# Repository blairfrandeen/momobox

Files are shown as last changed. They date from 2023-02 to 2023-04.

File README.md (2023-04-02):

# The Momobox
A build-it-yourself MP3 player for toddlers, and maybe for adults too. 3D-print your own custom figurines (we call them _Momies_) and pair them with your favorite stories, songs, or audiobooks. If you have a 3D printer and the ability to solder, you can build one of these for roughly the same cost as a commercial [Toniebox](https://us.tonies.com/pages/toniebox), and without the long-term cost of ownership. Plus, the momobox and the associated momies are distinctly yours!

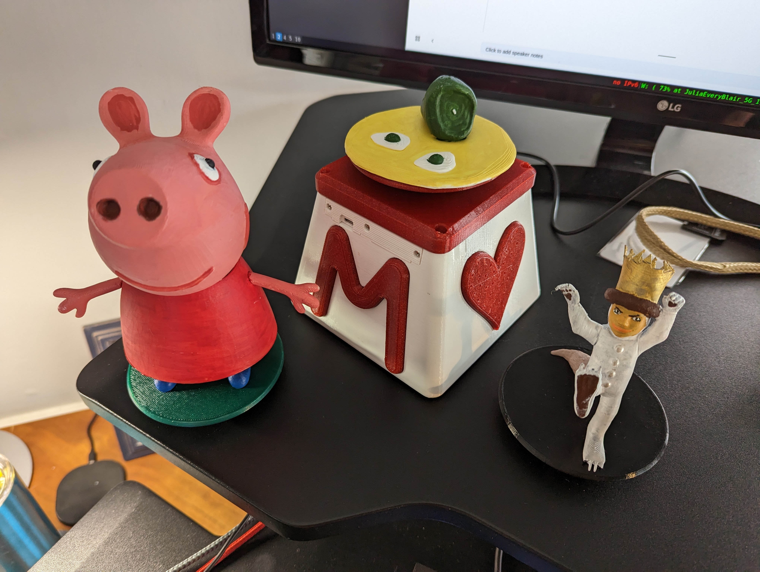
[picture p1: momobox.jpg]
Here's a momobox!


The momobox started as a toy I built for my daughter, who we call Momo, during my batch at [the Recurse Center](https://www.recurse.com). It runs on a Raspberry Pi Pico, and incorporates an RFID sensor, speaker, SD card, and a 3D-printed enclosure and momies.

## You Can Build One Too!
Take a look at the [project wiki](https://github.com/blairfrandeen/momobox/wiki) for resources and to get started. At this time the project is not fully documented - if you'd like support, encouragement, or get stuck during the build, please feel free to reach out!

## 3D Printed Components
The design for the 3D printed components lives in [OnShape](https://cad.onshape.com/documents/79b0dabc494fde770de26b57/w/b19bbc68ed3995e5b344c842/e/d2a39d4dcadbb5ff28daf759).

## Materials
Materials currently on order are stored in this [Google Sheet](https://docs.google.com/spreadsheets/d/11zDQTo5MPM0dLdLS7p9JRmXvDPAh0dKTZ6d4dLGUlPc/edit?usp=sharing). A finalized bill of materials should go in this section once an initial build configuration has been selected.

## Resources
List of learning & technical resources that can be used to complete this project:
- [Raspberry Pi Documentation](https://www.raspberrypi.com/documentation/computers/getting-started.html)
- [Uploading to Raspberry Pi Pico without Thonny](https://mikeesto.medium.com/uploading-to-the-raspberry-pi-pico-without-thonny-53de1a10da30)
- [Adafruit](https://learn.adafruit.com/) - Some beginning elex tutorials and components
- [Simple MP3 Audio Playback With Raspberry Pi Pico](https://embeddedcomputing.com/technology/processing/interface-io/simple-mp3-audio-playback-with-raspberry-pi-pico) - Good tutorial to start working next.
- [Raspberry Pi Pico Tutorial with battery hookup](https://www.raspberrypi.com/tutorials/raspberry-pi-pico-iron-man-arc-reactor/)
- [Tom's Hardware Pico Page](https://www.tomshardware.com/news/raspberry-pi-pico-tutorials-pinout-everything-you-need-to-know)
- [Raspberry Pi Projects Page](https://projects.raspberrypi.org/en/projects/getting-started-with-the-pico) - Getting started with Pico tutorial

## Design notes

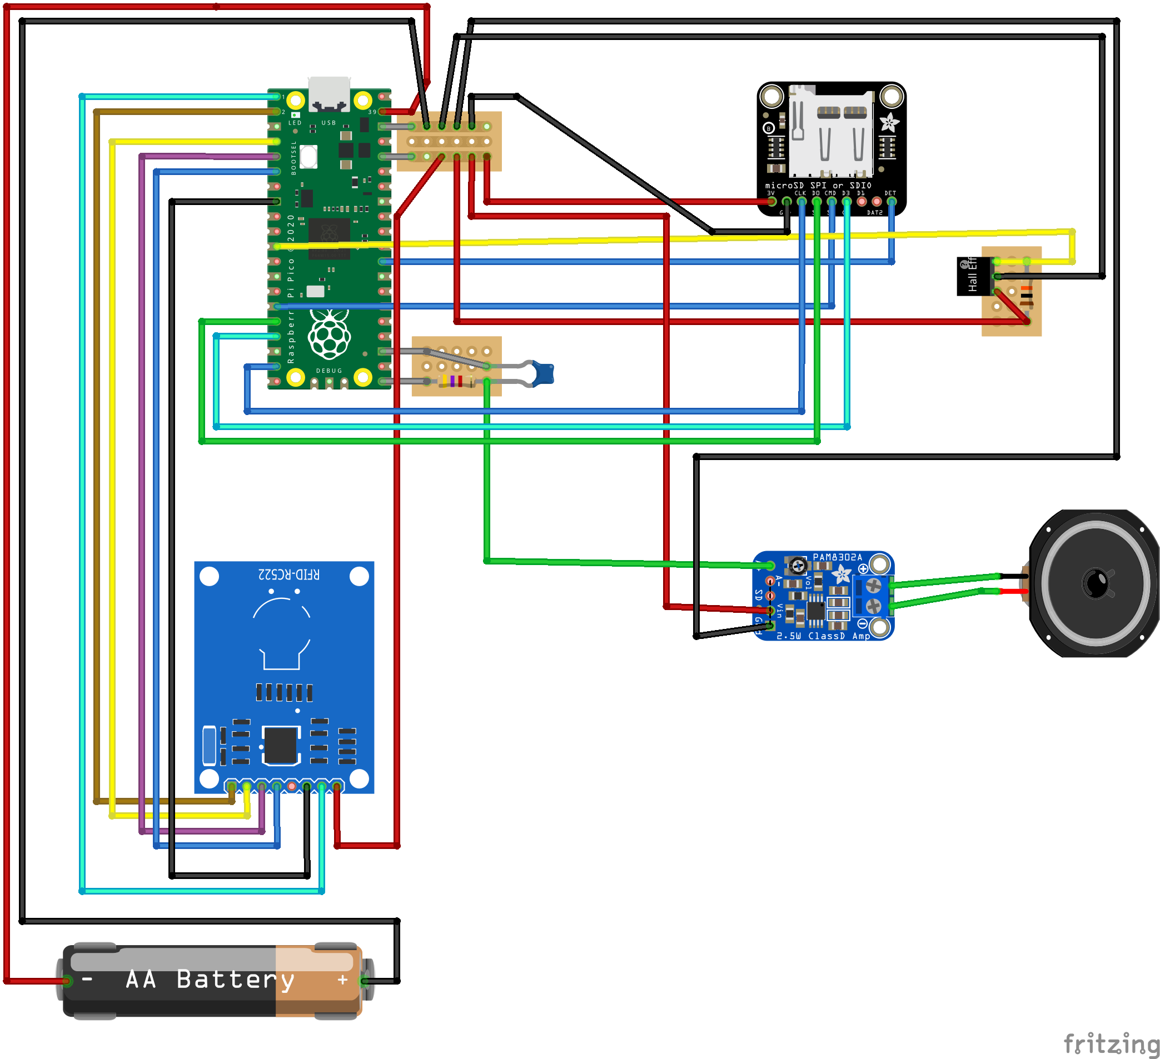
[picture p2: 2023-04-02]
schematics/momobox_bb.png

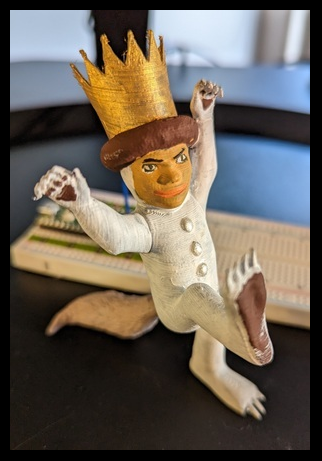
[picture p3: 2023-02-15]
wildmax.jpg

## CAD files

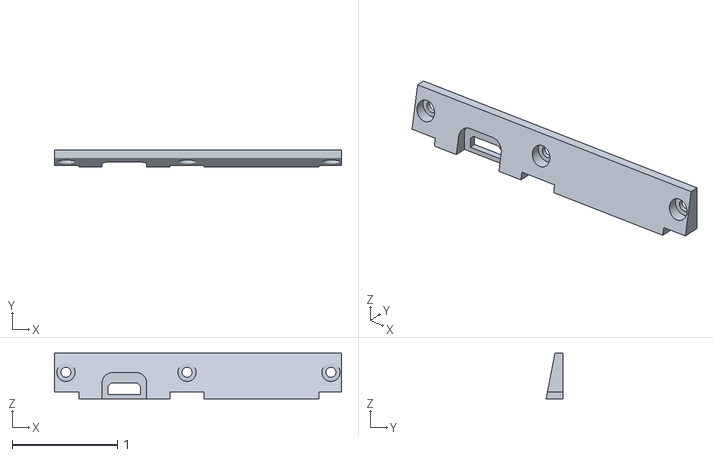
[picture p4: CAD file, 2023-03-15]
packaging/momobox_base_coverplate.stl
2.73 x 0.161 x 0.435

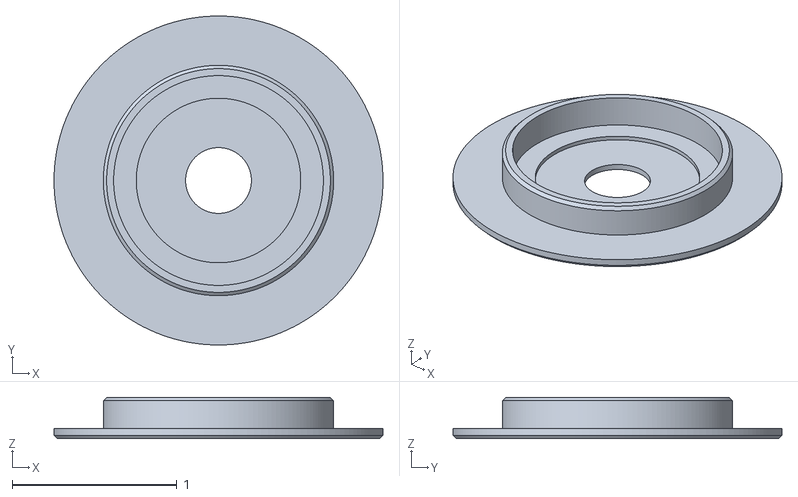
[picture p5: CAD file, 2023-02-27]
stage_cap.stl
2.00 x 2.00 x 0.25

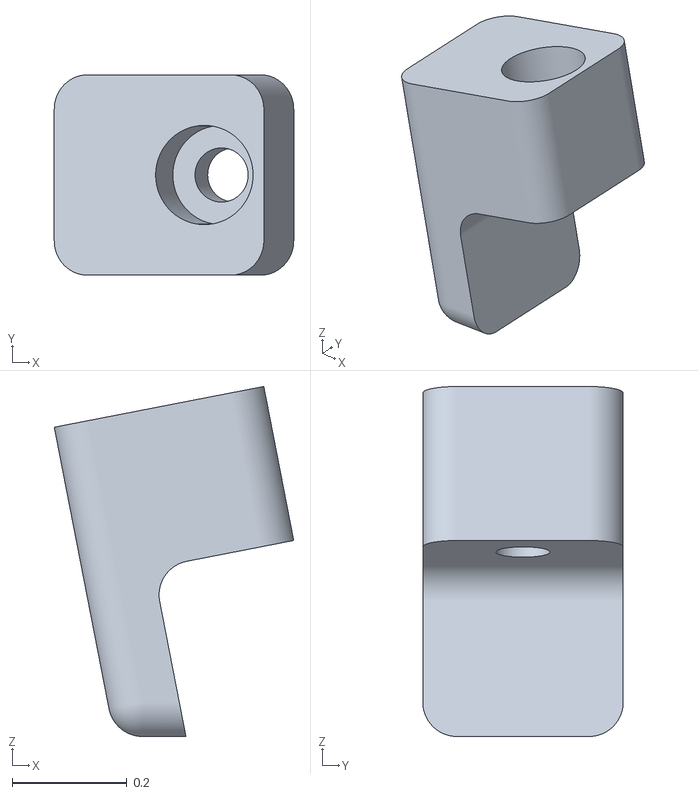
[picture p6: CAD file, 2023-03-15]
packaging/momobox_speaker_clip.stl
0.418 x 0.35 x 0.611

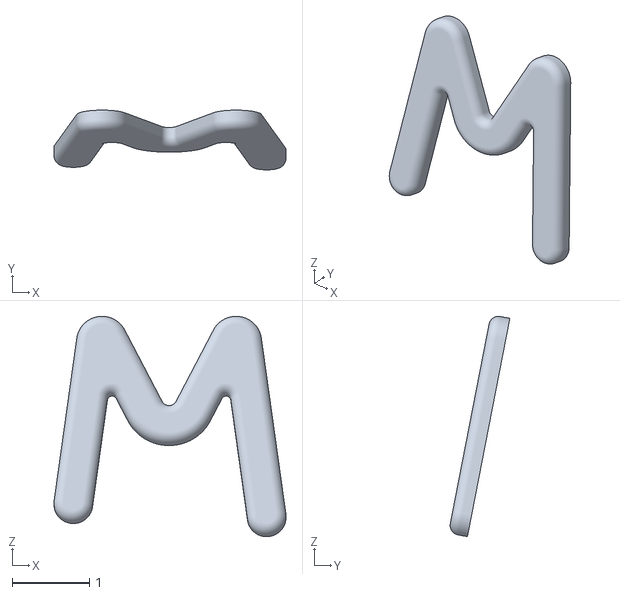
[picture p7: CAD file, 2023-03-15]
packaging/momobox_m.stl
3.00 x 0.773 x 2.85

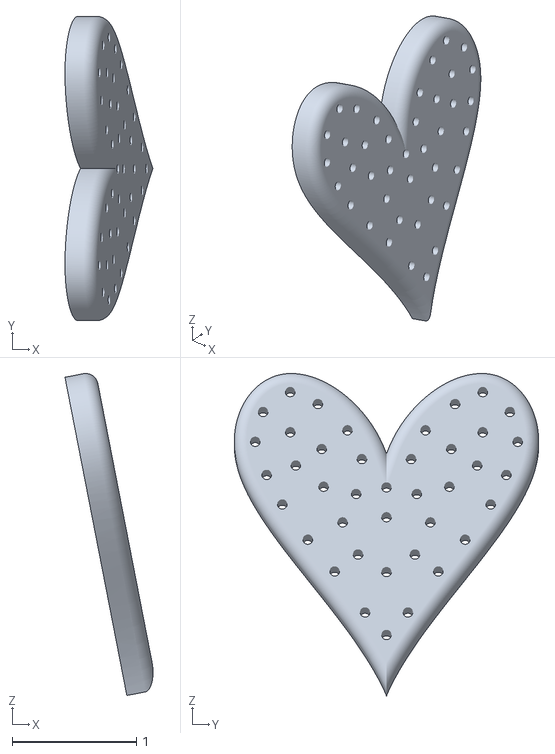
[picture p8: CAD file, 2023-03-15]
packaging/momobox_heart_front.stl
0.708 x 2.45 x 2.59

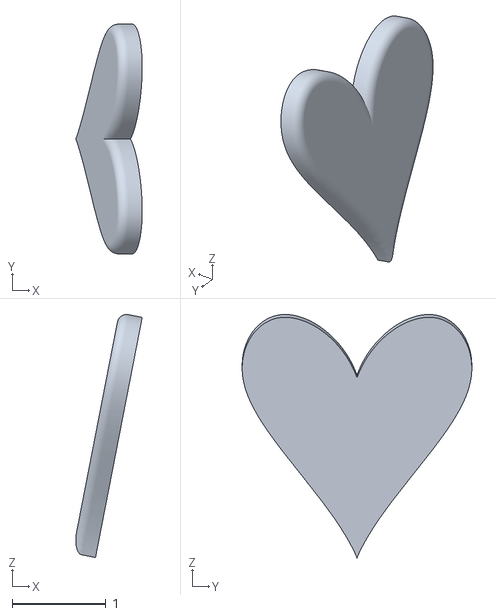
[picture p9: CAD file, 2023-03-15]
packaging/momobox_heart_back.stl
0.708 x 2.45 x 2.59

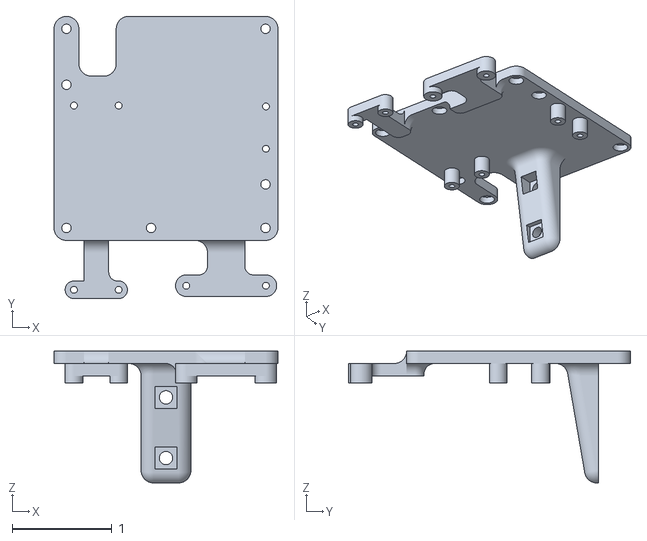
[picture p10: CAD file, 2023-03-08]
packaging/momobox_board_mount.stl
2.25 x 2.83 x 1.33

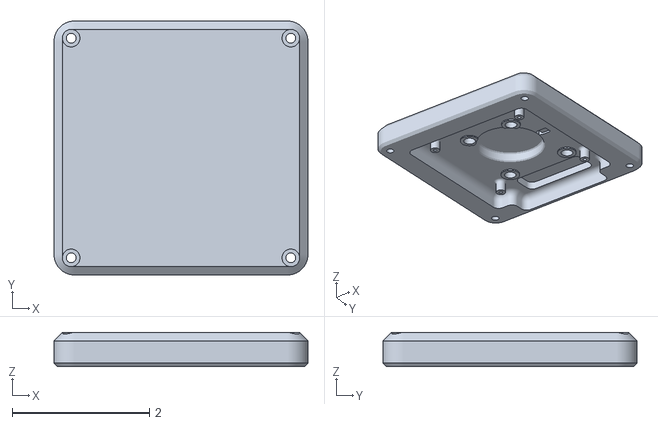
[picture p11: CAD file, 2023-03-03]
packaging/momobox_base_lid.stl
3.70 x 3.70 x 0.5

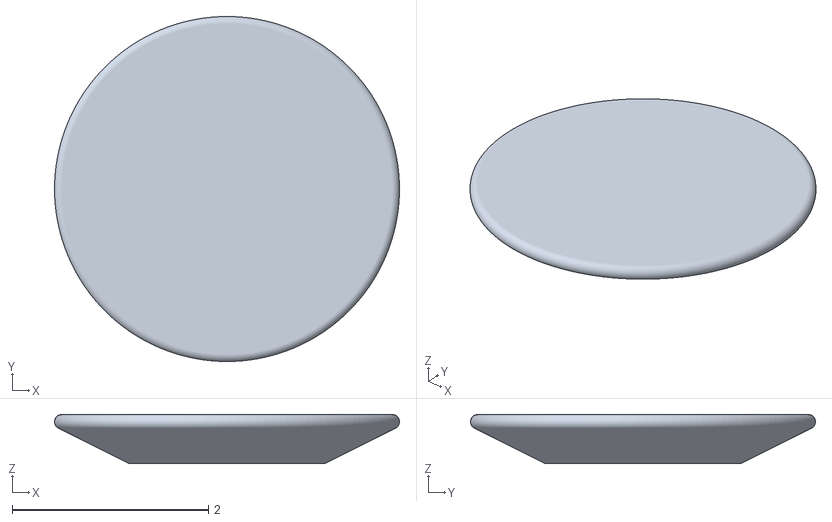
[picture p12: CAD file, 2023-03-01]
packaging/stage_top.stl
3.51 x 3.51 x 0.5

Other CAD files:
packaging/momobox_m_mirror.stl
packaging/stage_cap.stl

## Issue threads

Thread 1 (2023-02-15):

Start Bill of Materials

blairfrandeen, 2023-02-15:
Start a basic bill of materials, either in markdown table or csv format. Should include the following columns:
- Component Name
- Quantity Required
- Description or Notes
- Source (link to purchase)
- Price

Okay for this to be wrong / incomplete. Also okay for components to be identified as needed and not fully specified. Multiple options for components also okay.

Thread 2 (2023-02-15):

Set up MicroPython Development Environment

blairfrandeen, 2023-02-15:
The "official" method of talking to the Raspberry Pi Pico is through the Thonny editor, which isn't my preferred development environment.

Check out [this article](https://mikeesto.medium.com/uploading-to-the-raspberry-pi-pico-without-thonny-53de1a10da30) and see if I can't get Raspberry Pi Pico to talk directly to VSCode, which is my editor of choice.

blairfrandeen, 2023-02-24:
Happy with the current approach of editing on my local machine, and then pushing files to the pico which is connected at `/media/blair/CIRCUITPY`. CircuitPy is more friendly to this approach than MicroPython.

Closed 2023-02-24.

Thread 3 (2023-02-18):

Pi Pico Basics

blairfrandeen, 2023-02-18:
Need to learn to program some fundamentals on the Pi. Issue is closed when I can do the following:

- [ ] control a program by opening or closing a physical switch (or connect a wire on the breadboard)
- [ ] write and retrieve a value that is persistently stored on the Pi
- [ ] copy a file from my computer to the Pi
- [ ] read from a file on the Pi
- [ ] delete a file from the Pi

blairfrandeen, 2023-02-18:
- [ ] implement logging on the Pi
- [ ] crash a program and then retrieve the stack trace

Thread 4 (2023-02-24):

Box Lid Design Issues

blairfrandeen, 2023-02-24:
- [x] Magnet needs to be positively secured to top of lid (maybe just use superglue)
- [x] Bosses for inserts need to be larger diameter so they don't deform when insert installed
- [x] Verify positive separation between magnet and RC522 board
- [x] Need clocking feature between lid & base
- [x] Make material between magnet and top of lid as thin as possible
- [x] Not enough wire routing space for RC522 harness

Closed 2023-03-16.

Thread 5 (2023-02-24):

Try architecture without hall sensor

blairfrandeen, 2023-02-24:
Current setup for board includes a hall effect sensor, that toggles when magnets are connected. It may be simpler to just keep querying the RFID board, and if the RFID chip has been removed, then stop playing.

Should be functionally the same, but may be worse for power consumption, which so far hasn't been modeled or thought about.

blairfrandeen, 2023-03-16:
Tried this, and it's not the right way to go.

Having the RFID sensor continually querying to check for status, whether playing or not, is not going to be great for power consumption. I got it to work (code didn't get uploaded to GitHub yet), and the unit was very unresponsive. Took about 3 seconds from removing the Momie from the top of the box until it stopped playing; hall sensor in contrast is practically instantaneous.

Closed 2023-03-16.

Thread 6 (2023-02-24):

Speaker Mount points don't work

blairfrandeen, 2023-02-24:
Speaker mount points are not easy to work with; no good tool access, not even worth trying to get the square nuts into the bottom mount points. Needs to be rethought.

Best idea so far: Passive slot at the bottom of the box that accepts the speaker flange. Maybe keep improved screw bosses near opening of top of box, but there is also an option to make a flexured post or latch to simply snap the speaker into place.

blairfrandeen, 2023-03-15:
Fixed this on V8 of the enclosure. Speaker is secure. 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

Closed 2023-03-15.

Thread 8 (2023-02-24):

Incorporate Battery

blairfrandeen, 2023-02-24:
Need to incorporate a battery so that momobox runs wirelessly.

blairfrandeen, 2023-03-16:
So far I've only incorporated AA batteries. At this point they need to be manually removed and recharged, which requires removing the lid from the top of the box; not ideal, but workable for MVP.

Closed 2023-03-16.

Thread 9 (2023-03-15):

High Pitched audio whine

blairfrandeen, 2023-03-15:
Good explanation and possible solution here: https://forums.adafruit.com/viewtopic.php?t=188012

And here:
https://forums.adafruit.com/viewtopic.php?f=8&t=187616#p909859

Need to order some 10nF and 100nF capacitors and check my resistor supply, then check on a breadboard

blairfrandeen, 2023-03-21:
Using a 10k resistor and a 100nF (0.1 μF) capacitor seems to work! Leaving open until fully documented.

blairfrandeen, 2023-04-02:
Documented in 979b3bd

Closed 2023-04-02.

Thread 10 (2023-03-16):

Lid and board mount design issues

blairfrandeen, 2023-03-16:
- [ ] Board mount fasteners to lid are not accessible. Removing the board mount requires partial removal of the pico and the SD card board. Thru-holes have been added to the board mount, and corresponding bosses need to be added to the lid.
- [ ] Battery clip blocks board mount fasteners on back of board
- [ ] Harness routing features, particularly for RFID harness, should be added to ensure that nothing gets pinched when the lid is closed.

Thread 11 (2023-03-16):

Implement replacement for heat-set inserts

blairfrandeen, 2023-03-16:
Heat-set inserts are great, and also expensive. They cost about $17 on McMaster, and I'd like to offer users a cheaper solution.

Will probably go with some sort of press-in or slot-in hex or square nuts. Currently the heat-set inserts are used in the lid to box connection and the RFID board to lid connection.

The latter could be tapped M3 fasteners since the RFID board nominally only goes on once; the lid to box connection benefits greatly from being threaded.

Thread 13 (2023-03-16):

Better volume control

blairfrandeen, 2023-03-16:
Currently the only option for volume control is to turn the screw on the audio board. End user's key stakeholder requests easier adjustment.

Not sure how to implement this easily, may take some creative thought.

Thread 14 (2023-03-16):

RFID light stays on

blairfrandeen, 2023-03-16:
Currently the red RFID board LED is on whenever the unit is powered. Nice to see that it's on, but the light is off-center and not there intentionally. One or more dedicated LEDs to communicate status would be better

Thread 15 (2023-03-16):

Box Bottom Design

blairfrandeen, 2023-03-16:
Current box design is monolithic. Looks nice, but I think there are advantages to a separate bottom:

- iterating on the box design likely doesn't require a new bottom. In the latest print the bottom took 3 hr.
- a totally flat bottom separates from the bed (warps) prematurely
- a ribbed bottom requires support material which is hard to remove.

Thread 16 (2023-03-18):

Put momobox to sleep when not being used

blairfrandeen, 2023-03-18:
The firmware runs continuously when the batteries are connected. Goal is to have the pico go into sleep mode after some amount of idle time, and then awake upon a signal from the hall sensor.

A good starting point with resources is here: https://ghubcoder.github.io/posts/deep-sleeping-the-pico-micropython/

May be better to also read this post about dormant and sleep modes: https://ghubcoder.github.io/posts/awaking-the-pico/

This is micropython based (momobox currently uses circuit python), so may not be fully applicable.

A good thing to start with is to measure the current draw from the batteries during the following operations:
- idle time
- RFID request
- playing a song
- song paused

blairfrandeen, 2023-10-17:
Some measurements made with a DMM:

Condition | Current Draw [mA]
--- | ---
Standby | 65.6
Playing | 70-110
Paused | 68.6
RFID Chip present without magnet | 70.6
Magnet present, no RFID | 69.5
RFID, no magnet, after magnet had been activated | 74
Crashed | 45

The 2X batteries I'm using have a capacity of 1500 mAh (3000 total). 3000 mAh / ~70 mA =~ 42 hours
This operating time matches our experience with the momobox so far, although we typically get to about 24-30 hours before it turns off.

It may be promising to reduce power usage by rewriting the firmware in a lower level language that isn't constantly running an interpreter. For comparison, running "blinky" in Rust only takes 22-24 mA

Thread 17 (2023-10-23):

Integrated Rechargeable Battery

blairfrandeen, 2023-10-23:
We're tired of having to swap the batteries every day. While it would be nice to reduce power consumption (see #16), it's also necessary that it can charge simply by plugging it in.

Some very preliminary research: https://www.circuitbasics.com/how-to-power-your-raspberry-pi-with-a-lithium-battery/

As I understand it I'll need three components, which I now have on order:
- [A re-chargeable lithium-ion battery (3.7 V)](https://www.digikey.com/en/products/detail/adafruit-industries-llc/1781/5054543)
- [A voltage regulator board](https://www.digikey.com/en/products/detail/adafruit-industries-llc/4654/12697636) - This keeps the power to the Pico at 5 V regardless of the battery state of charge
- [A battery charge controller](https://www.digikey.com/en/products/detail/adafruit-industries-llc/1904/5054545)

My hope is to use the above together so that the user can plug in directly to the charge controller, and still be able to use the box when it's plugged in. At the very least, not need to reconfigure anything while charging. If this fails, I bought a more expensive all-in-one board that I can use instead: https://www.digikey.com/en/products/detail/adafruit-industries-llc/2465/5356834

Also purchased another Pico with pre-soldered headers to try this with, as well as a second breadboard.

While I'm waiting for parts to arrive, I have some CAD work to do to figure out how I'm going to mount two additional boards and a new battery within the existing housing. I'll probably want to move the Pico back and put the charge port in its place, and 3D print a new battery clip.

blairfrandeen, 2023-11-06:
Made some progress on this; I'd call it pretty hacked together. I redesigned the board mount to remove the AA battery holder, and to re-arrange the boards to make space for the charge controller and voltage regulator. I made a single-piece articulating clamp to hold the battery and glued it to the inside of the chassis.

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

The problem with this arrangement, that I missed as I was doing the CAD, is that you can't plug and un-plug the battery with the Pico in place, and you can't plug into the Pico at all if the battery board is there. You have to unscrew and rotate the Pico slightly to access either plug; not ideal, but it works. I did not want to completely re-solder the Pico on this iteration, so some sacrifices were made and janky-ness was accepted in the name of getting it together and learning something.

I would like to figure out how to do the battery charging entirely through the Pico. I have another set-up on a breadboard I'll have to work with to figure out if that's safe/possible.

The battery rated at 2200 mAh kept the Pico on for about as long as the 2X AA batteries kept it on, and those supposedly have more capacity. See #16 for more context on battery capacities.

I left the momobox on overnight to drain the battery and see if I could re-charge it. It sure drained, but when I plugged it in it wouldn't turn all the way on; the speaker made some weird buzzing noises. My hypothesis is that the single USB connector couldn't supply enough current to both power the Pico and charge the battery, so the Pico kept trying to boot and then failed. I didn't let this experiment go on forever; it's possible that the battery would have eventually gotten enough charge to allow the momobox to boot, but I didn't wait.

Instead, I replaced the SD card access slot with a slider switch, and the momobox can be charged with the switch in the 'off' position. It is now a fully functional and rechargeable unit, with the caveat that it needs to be turned off to recharge if the battery drains.

The momobox runs on battery, or while plugged in.

The next step would be to re-think a lot of the internal packaging, and ultimately buy down some tech debt and overhaul the entire CAD model. This process was started over the weekend, and needs to continue until the model is both easier to work with and easier to assemble. Good progress.

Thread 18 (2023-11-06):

On-board logging

blairfrandeen, 2023-11-06:
I would like to replace all of the print statements with log statements, and I would like the momobox to keep track of some basic on-board logging. Some thoughts on the logger:

- I need a switch to make the Pico read-only. As described [here](https://learn.adafruit.com/circuitpython-essentials/circuitpython-storage), the Pico can self-write to its own filesystem, or it can allow the PC its connected to to write, which is used for easily updating the code. The linked article suggests making a switch, and adding it to the boot.py file. I propose to add the following to boot.py:
```python
import board
import digitalio
import storage

switch = digitalio.DigitalInOut(board.GP22)
storage.remount(mount_path="/", readonly=not switch.value)
```
Currently GP22 is the pin that detects whether an SD card is inserted. What the code above would mean is that the file-system would be read-only (able to update the code) if the SD card was not present. Since the SD card is required to use the momobox, part of updating the onboard code would be to boot the momobox with the SD card removed.

- I would want to minimize and limit the size of the logs, since the on-board memory is limited to 1 MB, and some of that space is already spoken for. I know that the python logging module allows for this to some extent, so I'll have to implement it.
- On the subject of the above, it would be useful to minimize the size of the log file by minimizing log messages; it's okay to be terse

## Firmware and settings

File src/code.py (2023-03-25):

"""
Mockup for onboard logic for Momobox
"""
import time

import audiomp3
import audiopwmio
import board
import busio
import digitalio
import sdcardio
import storage

import mfrc522

# Dictionary to map RFID codes to song/story path names
LIBRARY = dict()
with open("library.txt", "r") as lib:
    for line in lib:
        key, value = line.split(", ")
        LIBRARY[key.strip()] = value.strip()

# Controls how long the momobox can be paused (momie removed)
# before the song is stopped. After this amount of time, any
# momie placed on the box will start the song from the beginning
RESET_CLOCK_S = 15


class AudioPlayer:
    def __init__(self, hall_sensor, audio_out):
        self.audio = audiopwmio.PWMAudioOut(audio_out)  # board.GP16
        self.song = None
        self.decoder = None
        self.hall_sensor = digitalio.DigitalInOut(hall_sensor)  # GPIO Pin 18
        self.reset_clock: int = 0
        self.rfid_reader = rfid_reader_init()

        self.listen()

    def play(self):
        try:
            self.decoder = audiomp3.MP3Decoder(open(LIBRARY[self.song], "rb"))
        except KeyError:
            print(f"That song isn't registered!")
            print(f"RFID Key used: {self.song}")
            self.song = None
            return None
        except OSError as err:
            print(f"ERROR: {err}")
            print("File not on SD Card!")
            self.song = None
            return None
        self.audio.play(self.decoder)

    def pause(self):
        self.audio.pause()
        self.reset_clock = time.time()

    def resume(self):
        self.audio.resume()

    def unload(self):
        self.audio.stop()

    @property
    def is_playing(self):
        return self.audio.playing

    @property
    def is_paused(self):
        return self.audio.paused

    def listen(self):
        while True:
            if self.hall_sensor.value is True:
                # Figure out what to play
                if self.is_paused:
                    # See what's on the RFID reader:
                    new_song = read_rfid(self.rfid_reader)

                    time_paused = time.time() - self.reset_clock
                    # check that we still have the same song
                    # and that we haven't been gone too long
                    if new_song == self.song and time_paused < RESET_CLOCK_S:
                        self.resume()
                    else:  # start a new song
                        self.audio.stop()
                        self.song = new_song
                        self.play()
                elif not self.is_playing:
                    # play a new song
                    new_song = read_rfid(self.rfid_reader)

                    # Avoid repeating songs if momie left on top
                    if new_song != self.song:
                        self.song = new_song
                        self.play()
                else:
                    # Keep going!
                    pass
            else:
                if self.is_playing and not self.is_paused:
                    self.pause()
                #  if self.is_paused:
                #  time_paused = time.time() - self.reset_clock
                #  print(time_paused, time.time(), self.reset_clock)
                #  if time_paused < RESET_CLOCK_S:
                #  print("Timeout, stopping!")
                #  self.audio.stop()


def rfid_reader_init():
    sck = board.GP2
    mosi = board.GP3
    miso = board.GP4
    spi = busio.SPI(sck, MOSI=mosi, MISO=miso)

    cs = digitalio.DigitalInOut(board.GP1)
    rst = digitalio.DigitalInOut(board.GP0)
    rfid = mfrc522.MFRC522(spi, cs, rst)

    rfid.set_antenna_gain(0x00 << 4)
    return rfid


def read_rfid(rfid_reader):
    while True:
        print("Making RFID request")
        (status, tag_type) = rfid_reader.request(rfid_reader.REQALL)
        if status == rfid_reader.OK:
            (status, raw_uid) = rfid_reader.anticoll()
            if status == rfid_reader.OK:
                print("Found RFID key: ", end="")
                rfid_data = "{:02x}{:02x}{:02x}{:02x}".format(
                    raw_uid[0], raw_uid[1], raw_uid[2], raw_uid[3]
                )
                print(rfid_data)
                return rfid_data


def test_hall():
    hall = digitalio.DigitalInOut(board.GP8)
    while True:
        print(hall.value)
        time.sleep(0.2)


def mount_sd_card():
    # Mount SD card
    p1 = digitalio.DigitalInOut(board.GP22)  # assign pin for DET
    try:
        assert p1.value is True  # no SD card inserted
    except AssertionError:
        print("NO SD Card Inserted!")
        exit(-1)
    spi = busio.SPI(board.GP14, board.GP11, board.GP12)
    cs = board.GP13
    sdcard = sdcardio.SDCard(spi, cs)
    vfs = storage.VfsFat(sdcard)
    storage.mount(vfs, "/sd")


def main():
    stop_time: int = 0  # state variable, when was most recent song stopped
    most_recent: int = None  # most recent song id
    pause_ts: float = 0.0  # last pause

    hall_sensor = board.GP8
    audio_out = board.GP16
    mount_sd_card()
    #  read_rfid()
    player = AudioPlayer(hall_sensor, audio_out)
    #  test_hall()


if __name__ == "__main__":
    main()

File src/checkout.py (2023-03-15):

import os

import audiomp3
import audiopwmio
import board
import busio
import digitalio
import storage
import sdcardio

import code

# Test that SD card is working
def test_sd_mount():
    print("Checking SD Card")
    spi = busio.SPI(board.GP14, board.GP11, board.GP12)
    cs = board.GP13
    sdcard = sdcardio.SDCard(spi, cs)
    vfs = storage.VfsFat(sdcard)
    storage.mount(vfs, "/sd")
    try:
        sd_mount = os.listdir("/sd")
        print("SD Card mounted at '/sd'")
        total_size = 0
        for file in sd_mount:
            total_size += os.stat(f"/sd/{file}")[6]
        print(f"{len(sd_mount)} files")
        print(f"{total_size} bytes")
        storage.umount(vfs)
        sdcard.deinit()

    except OSError:
        print("SD Card not mounted!")


def test_hall_sensor():
    print("Checking hall sensor")
    hall = digitalio.DigitalInOut(board.GP8)
    if hall.value is True:
        print("Please remove magnet from top of Momobox")
        while hall.value is True:
            pass
    print("Please place magnet on top of Momobox.")
    while hall.value is False:
        pass
    print("Magnet detected, hall sensor is working!")


def test_audio():
    print("Playing Audio Test...", end="")
    audio = audiopwmio.PWMAudioOut(board.GP16)
    decoder = audiomp3.MP3Decoder(open("soundcheck.mp3", "rb"))
    audio.play(decoder)
    while audio.playing:
        pass
    audio.stop()
    audio.deinit()
    print("Audio test complete!")


def main():
    test_sd_mount()
    test_audio()


if __name__ == "__main__":
    main()

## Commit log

2023-02-17 update README with BOM and WIP SW description
2023-02-17 Mock-up onboard logic
    Wrote a quick python script that mimics the intended onboard logic for
    the Momobox. Currently only runs in the console. Displays ASCII
    characters instead of actually playing songs, but this functionality can
    be replaced.
    Currently implements the intended logic for starting, stopping, and
    resuming play.
2023-02-19 add base stl
2023-02-19 docs: add first STL file to README
2023-02-20 Initial onboard player
    Set up initial code.py file which plays music on the Pi. Song filenames
    are hard-coded right now. Uses a fake "hall sensor" which checks for
    whether 3V3 is connected to GPIO pin 18. Disconnecting this lead causes
    selected song to pause; if left paused more than 5 seconds, a new song
    must be selected, similar to how the device should behave.
2023-02-24 add base lid and stage
    [momobox_base_lid.stl, stage_cap.stl, stage_top.stl]
2023-02-27 docs: remove switch from MVP description
2023-02-27 fix: off-center cap
    [stage_cap.stl]
2023-03-01 fix: off center stage top
    [stage_top.stl]
2023-03-03 fix/feat: base lid issues
    Added bosses for additional internal component mounting.
    Added hall sensor mount. Added wire clearance for RFID board. Magnet
    closer to top of box, larger bosses for RFID board.
    [momobox_base_lid.stl]
2023-03-03 fix: holes were poking through
    [momobox_base_lid.stl]
2023-03-08 packaging: update lid and board mount
    [momobox_board_mount.stl]
2023-03-08 fixes to board mount
    [momobox_board_mount.stl]
2023-03-13 WIP: hall sensor & state machine logic
2023-03-15 fix: antenna gain correction
    [code.py]
2023-03-15 fix: make sure to mount SD card
    [code.py]
2023-03-15 error handling for bad RFID card & missing files
    [code.py]
2023-03-15 test: add hall sensor checkout
2023-03-15 packaging update
    [momobox_base_coverplate.stl, momobox_heart_back.stl, momobox_heart_front.stl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]
2023-04-02 docs: add schematics
    [momobox.fzz]
